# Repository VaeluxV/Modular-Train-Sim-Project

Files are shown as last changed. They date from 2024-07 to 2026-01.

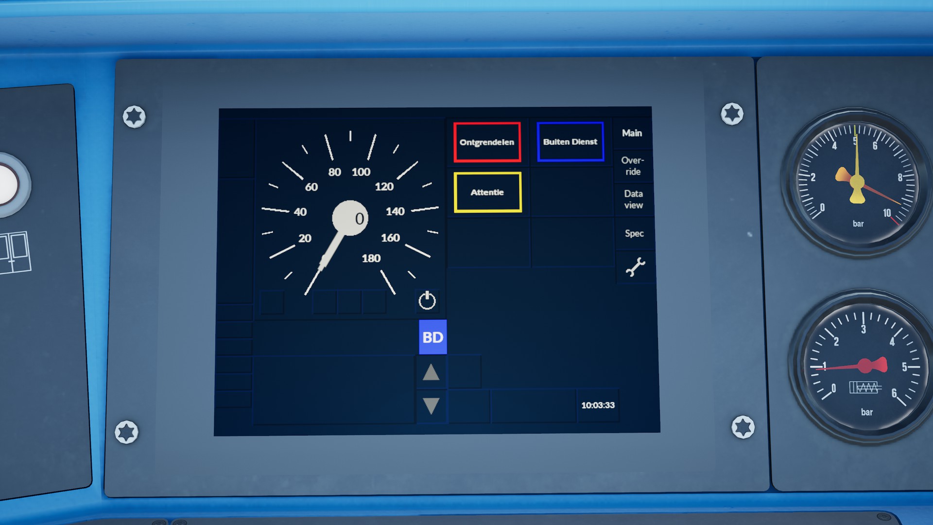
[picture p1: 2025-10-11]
BlenderFiles/Modules/References/20251010132142_1.jpg

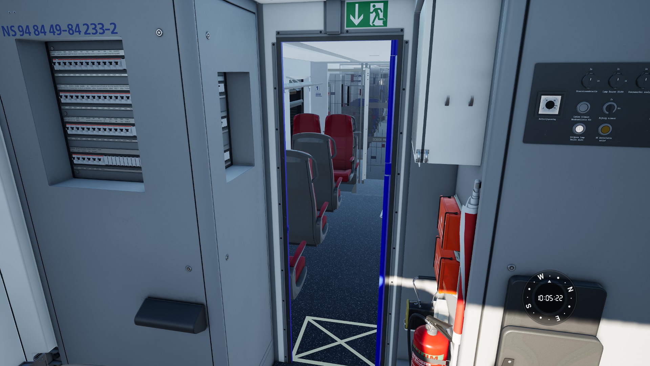
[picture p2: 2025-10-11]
BlenderFiles/Modules/References/20251010132330_1.jpg

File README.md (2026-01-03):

# Modular-Train-Sim-Project
A modular train sim cab project made for arduino. Communicating internally using UART, the main Arduino/Microcontroller requires HID capability (You can use a Pro Mico, Leonardo, etc. for this). 

This is still work in progress. ***This project is currently unfinished!***

<!-- <p xmlns:cc="http://creativecommons.org/ns#" >This work is licensed under <a href="https://creativecommons.org/licenses/by-nc-sa/4.0/?ref=chooser-v1" target="_blank" rel="license noopener noreferrer" style="display:inline-block;">Creative Commons Attribution-NonCommercial-ShareAlike 4.0 International <img style="height:22px!important;margin-left:3px;vertical-align:text-bottom;" src="https://mirrors.creativecommons.org/presskit/icons/cc.svg?ref=chooser-v1" alt=""><img style="height:22px!important;margin-left:3px;vertical-align:text-bottom;" src="https://mirrors.creativecommons.org/presskit/icons/by.svg?ref=chooser-v1" alt=""><img style="height:22px!important;margin-left:3px;vertical-align:text-bottom;" src="https://mirrors.creativecommons.org/presskit/icons/nc.svg?ref=chooser-v1" alt=""><img style="height:22px!important;margin-left:3px;vertical-align:text-bottom;" src="https://mirrors.creativecommons.org/presskit/icons/sa.svg?ref=chooser-v1" alt=""></a></p> --> 

<!-- <p>©VaeluxV</p> -->

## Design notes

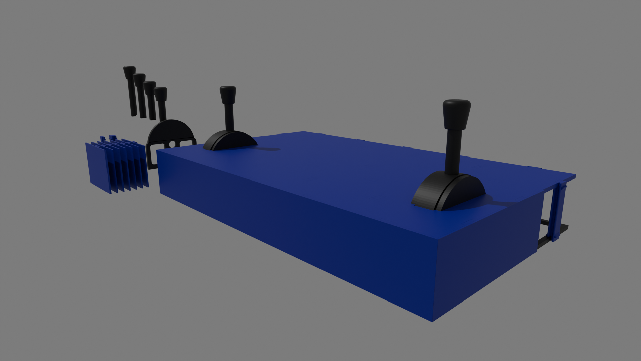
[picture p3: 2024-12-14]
BlenderFiles/Renders/MTS-v0.9.8-Render-2024-12-14-17-46-28.png

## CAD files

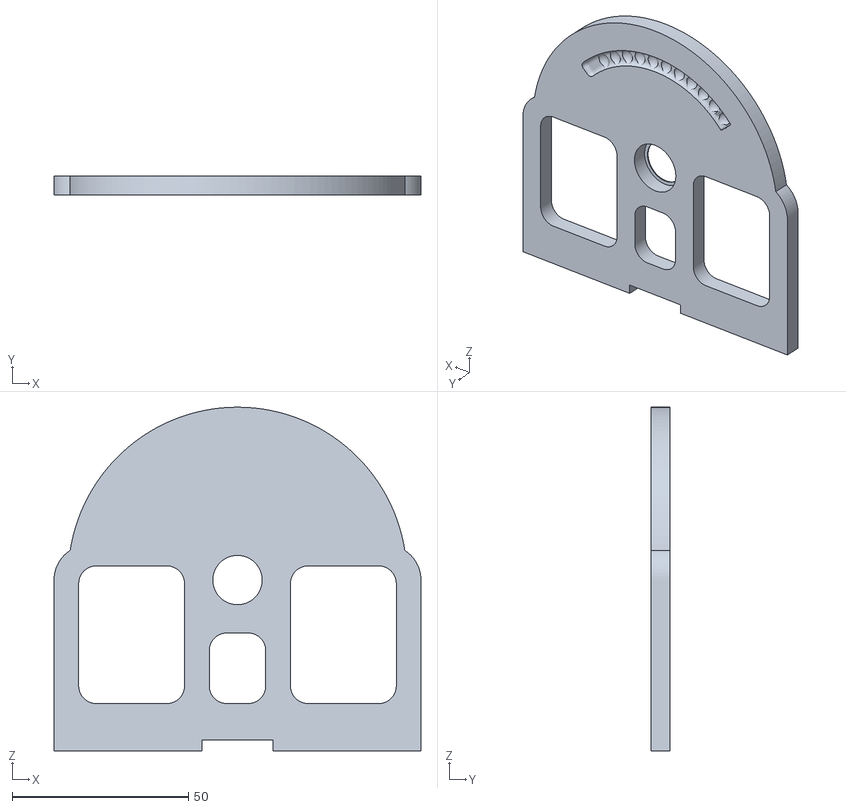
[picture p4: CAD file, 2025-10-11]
BlenderFiles/Modules/STLS/TEST-STL-0.11/Side-Lever-Indents-Flat-TS-v0.11.5.stl
104.0 x 5.40 x 97.4

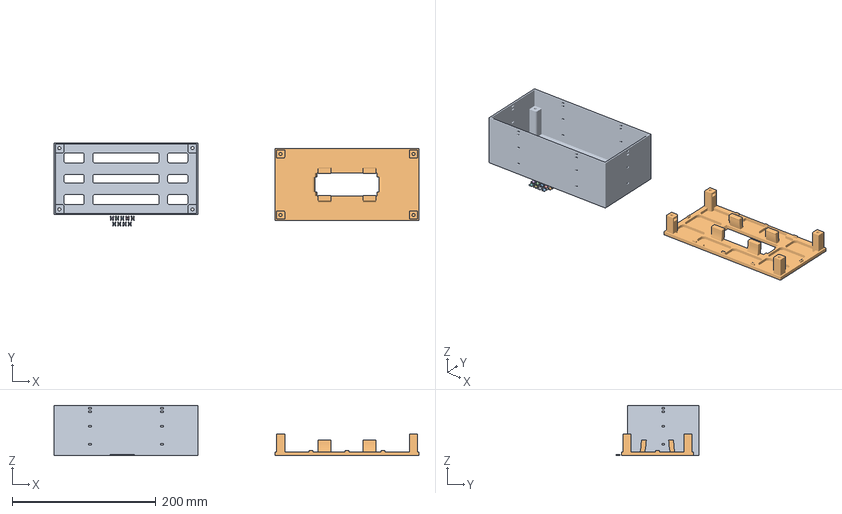
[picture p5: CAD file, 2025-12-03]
BlenderFiles/Modules/STLS/TEST-STL-0.12/TS-Lever-Module-v0.12.3mf
507.2 x 116.0 x 70.0 mm
TS-Bottom-Lever-Module-v0.12.0.stl
TS-Top-Lever-Module-v0.12.0.stl
TS-Clip-Lever-Module-v0.12.0.stl x 9

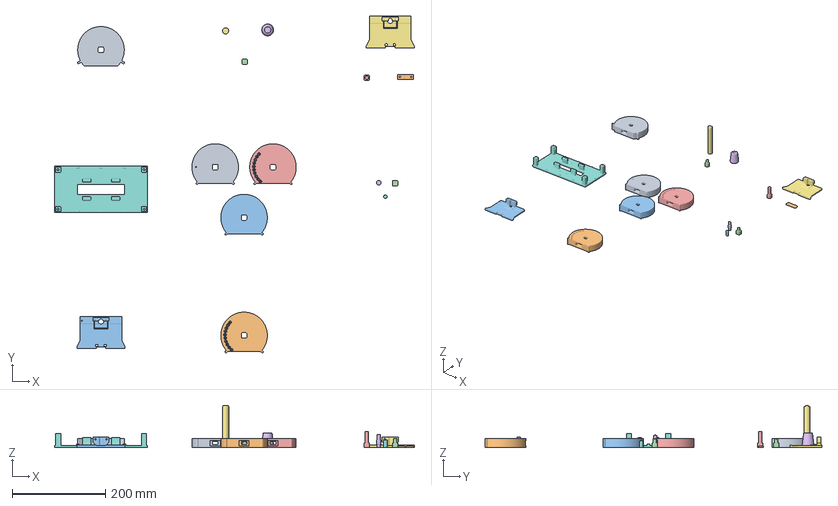
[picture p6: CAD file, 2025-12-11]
BlenderFiles/Modules/STLS/TEST-STL-0.13.x/TS-v0.13.3.3mf
772.9 x 723.2 x 91.1 mm
Lever-Base-TS-v0.13.3.stl
Lever-Base-Brake-Magnet-Layout-TS-v0.13.3.stl x 2
Lever-Side-Normal-Attachment-Magnet-TS-v0.13.3.stl
Lever-Shaft-Attachment-TS-v0.13.3.stl
Lever-Side-Hall-Magnet-Attachment-TS-v0.13.3.stl
Lever-Side-FrictionShaft-TS-v0.13.3.stl
Lever-Shaft-Friction-TS-v0.13.3.stl
Lever-Base-Standard-Magnet-Layout-TS-v0.13.3.stl
Lever-Side-FrictionShaft-Part-TS-v0.13.3.stl
Lever-Base-Standard-No-Magnet-Layout-TS-v0.13.3.stl
Lever-Shaft-OneSide-TS-v0.13.3.stl
Lever-FrictionShaft-OneSide-TS-v0.13.3.stl
Lever-Handle-Top-TS-v0.13.3.stl
Lever-Handle-Base-TS-v0.13.3.stl
Lever-Case-Top-TS-v0.13.3.stl

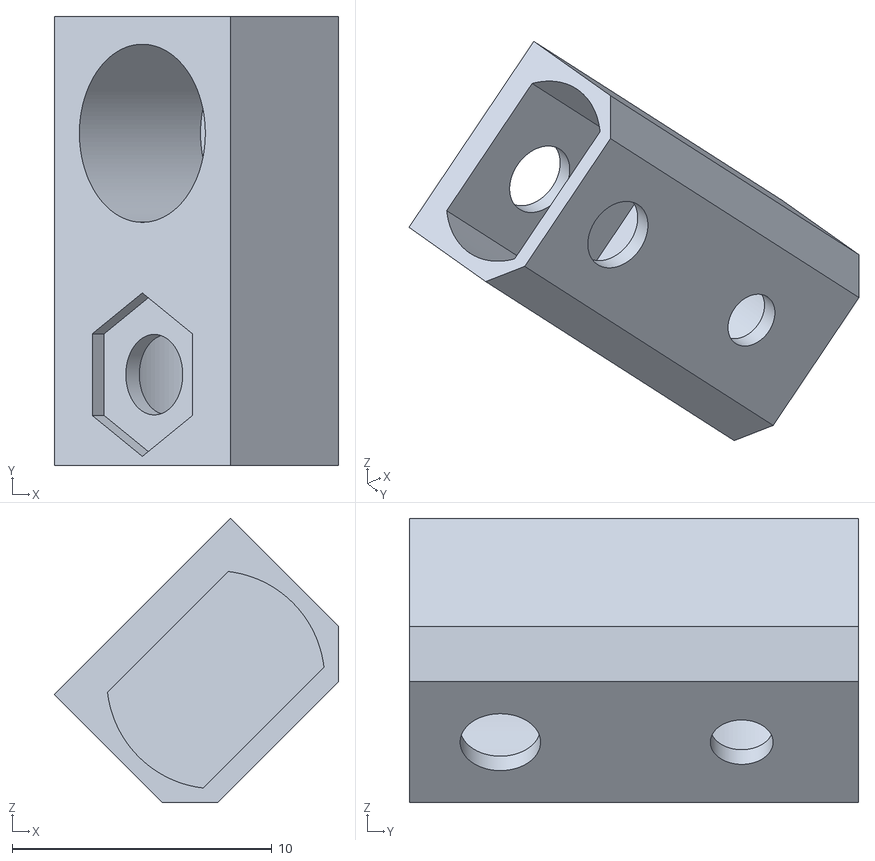
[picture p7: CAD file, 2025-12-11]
BlenderFiles/Modules/STLS/TEST-STL-0.14.x/0.14.0/Lever-Shaft-Magnet-Holder-TSv0.14.0.stl
11.0 x 17.3 x 11.0

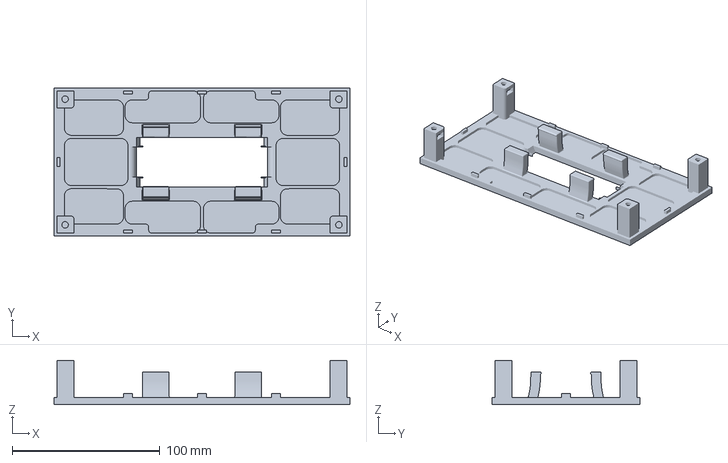
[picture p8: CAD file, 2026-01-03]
BlenderFiles/Modules/STLS/TEST-STL-0.15.x/Lever-Box-TS-v0.15.0.3mf
200.0 x 100.0 x 30.0 mm

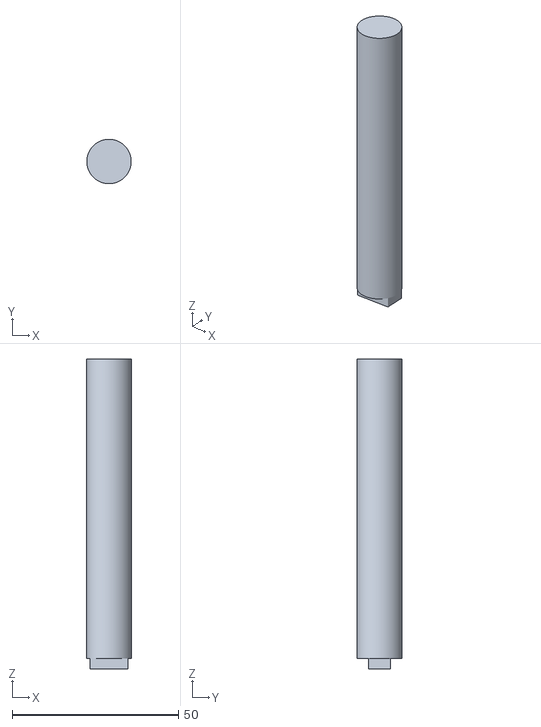
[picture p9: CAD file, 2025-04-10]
BlenderFiles/STLs/v0.10.5/levers_standard/handle_base_filled_long_lever-MTSP-v0.10.5.stl
13.4 x 13.4 x 93.1

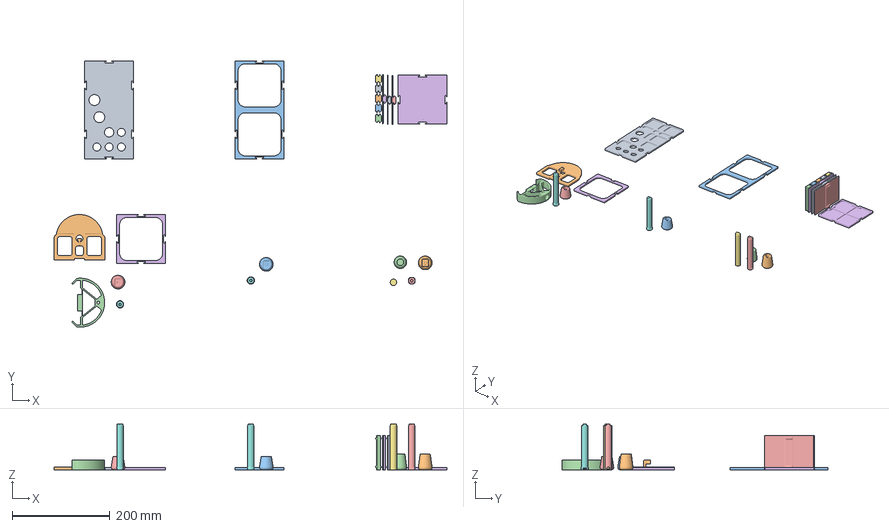
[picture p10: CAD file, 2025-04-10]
BlenderFiles/STLs/v0.10.5/MTSP-v0.10.5.3mf
802.6 x 543.8 x 93.1 mm
top_semi_hollow-MTSP-v0.10.1.stl
handle_top_long_standard_lever-MTSP-v0.10.5.stl
handle_top_standard_lever-MTSP-v0.10.4.stl x 2
handle_top_long_no_button_standard_lever-MTSP-v0.10.5.stl
handle_base_long_lever-MTSP-v0.10.5.stl
base_hollow-MTSP-v0.9.8.stl
handle_base_filled_long_lever-MTSP-v0.10.5.stl
handle_base_long_lever-MTSP-v0.10.4.stl x 2
connector_wall_corner_outer_single-MTSP-v0.9.8.stl x 2
common_side_sensor_lever-MTSP-v0.9.8.stl
bottom_hollow-MTSP-v0.10.1.stl
base_lever-MTSP-v0.10.4.stl
connector_standard-MTSP-v0.9.8.stl x 5
connector_wall-MTSP-v0.9.8.stl
top_semi_hollow-MTSP-v0.9.8.stl

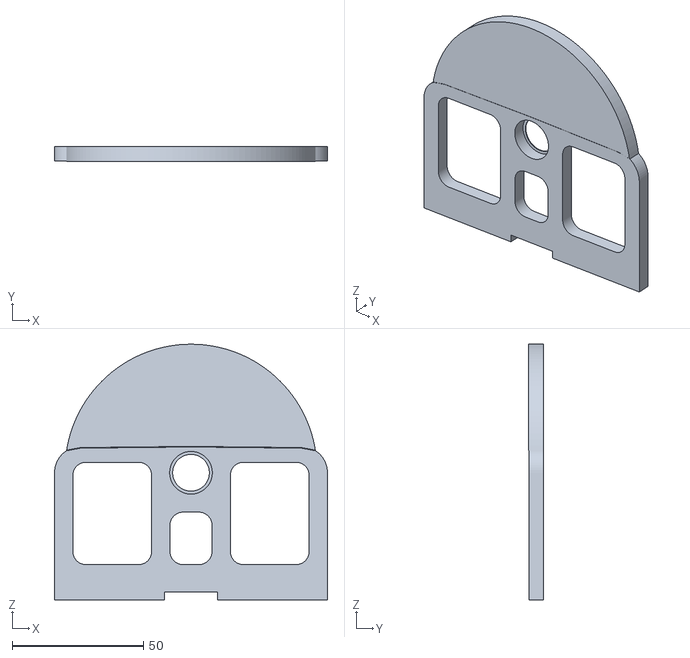
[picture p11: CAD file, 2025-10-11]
BlenderFiles/Modules/STLS/TEST-STL-0.11/Side-Lever-No-Indents-TS-v0.11.5.stl
104.0 x 5.60 x 97.4

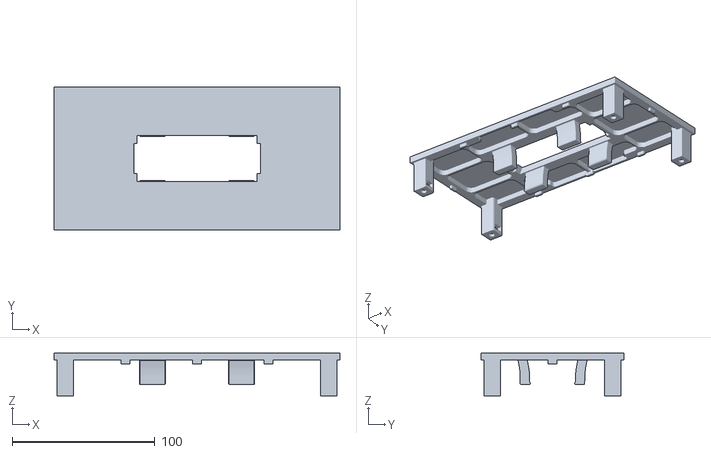
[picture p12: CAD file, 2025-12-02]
BlenderFiles/Modules/STLS/TEST-STL-0.12/TS-Top-Lever-Module-v0.12.0.stl
200.0 x 100.0 x 30.0

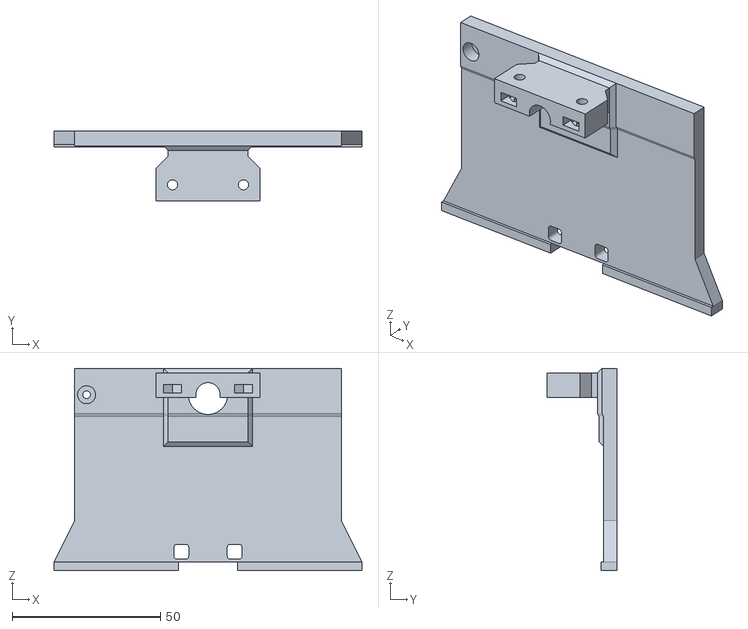
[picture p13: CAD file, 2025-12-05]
BlenderFiles/Modules/STLS/TEST-STL-0.13.x/Lever-Side-Normal-Attachment-Magnet-TS-v0.13.3.stl
104.0 x 23.5 x 68.3

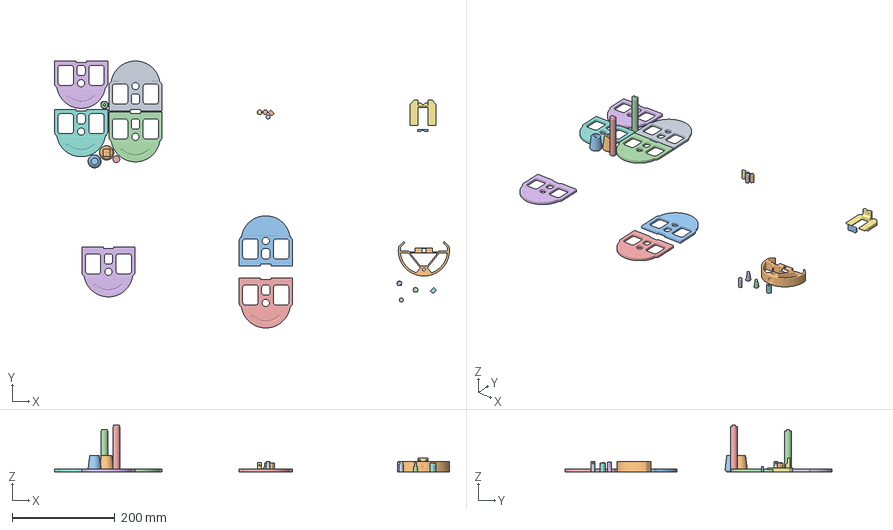
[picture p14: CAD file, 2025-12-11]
BlenderFiles/Modules/STLS/TEST-STL-0.14.x/0.14.0/TSv0.14.0.3mf
770.6 x 520.9 x 91.1 mm
Lever-Base-Side-TSv0.14.0.stl
Lever-Base-Middle-Generic-TSv0.14.0.stl
Lever-Base-Side-Magnets-TSv0.14.0.stl
Lever-Shaft-Friction-Attachment-TSv0.14.0.stl x 2
Lever-Base-Side-Notched-Smooth-TSv0.14.0.stl x 2
Lever-Shaft-Magnet-Attachment-TSv0.14.0.stl x 2
Lever-Shaft-Fricton-Extrusion-TSv0.14.0.stl
Lever-Shaft-Magnet-Holder-TSv0.14.0.stl x 2
Lever-Shaft-Friction-Part-TSv0.14.0.stl x 2
Lever-Shaft-Fricton-Extrusion-Part-TSv0.14.0.stl
Lever-Base-Side-Notched-Brakes-TSv0.14.0.stl
Lever-Base-Side-Notched-Center-TSv0.14.0.stl x 2
Lever-Handle-Button-Top-TSv0.14.0.stl
Lever-Handle-Basic-Top-TSv0.14.0.stl
Lever-Handle-Button-TSv0.14.0.stl
Lever-Handle-Basic-TSv0.14.0.stl

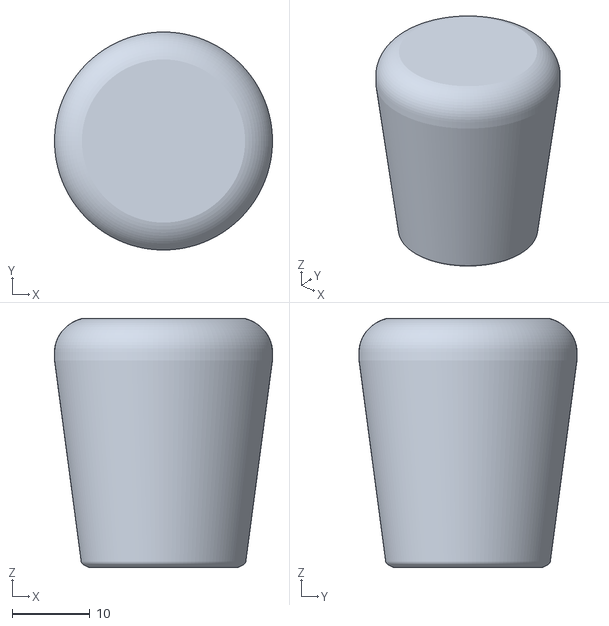
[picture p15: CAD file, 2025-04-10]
BlenderFiles/STLs/v0.10.5/levers_standard/handle_top_long_standard_lever-MTSP-v0.10.5.stl
28.1 x 28.1 x 32.1

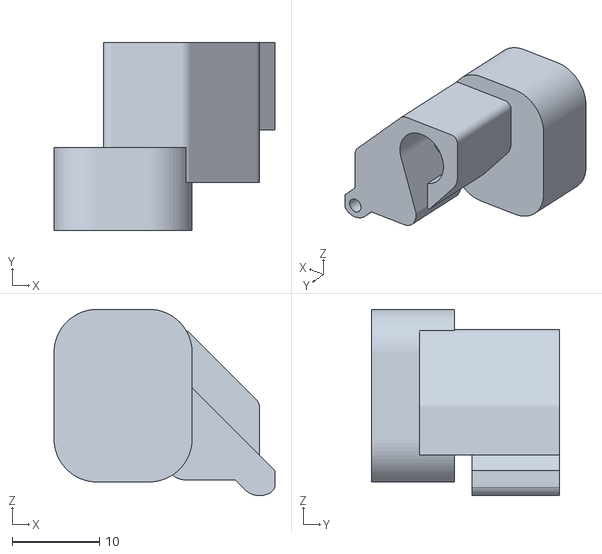
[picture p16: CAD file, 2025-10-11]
BlenderFiles/Modules/STLS/TEST-STL-0.11/Spring-Base-TS-v0.11.4.stl
25.3 x 21.5 x 21.4

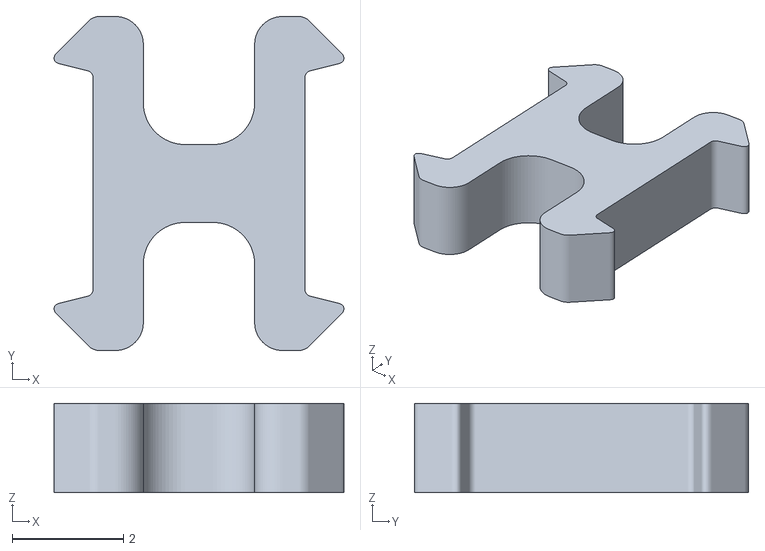
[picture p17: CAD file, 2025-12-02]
BlenderFiles/Modules/STLS/TEST-STL-0.12/TS-Clip-Lever-Module-v0.12.0.stl
5.21 x 6.00 x 1.60

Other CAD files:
BlenderFiles/Modules/STLS/TEST-STL-0.15.x/Top-Lever-Box-TS-v0.15.0.stl
BlenderFiles/Modules/STLS/TEST-STL-0.13.x/Lever-Base-Standard-No-Magnet-Layout-TS-v0.13.3.stl
BlenderFiles/Modules/STLS/TEST-STL-0.14.x/0.14.0/Lever-Shaft-Friction-Attachment-TSv0.14.0.stl
BlenderFiles/STLs/v0.10.5/levers_standard/handle_top_long_no_button_standard_lever-MTSP-v0.10.5.stl
BlenderFiles/Modules/Older versions/TrainSim-v2026.01.03.blend
BlenderFiles/Modules/Older versions/TrainSim-v2026.01.04.blend
BlenderFiles/Modules/Older versions/TrainSim-v2026.01.05.blend
BlenderFiles/Modules/STLS/TEST-STL-0.11/Experimental-TS-v0.11.2.3mf
BlenderFiles/Modules/STLS/TEST-STL-0.11/Experimental-TS-v0.11.5.3mf
BlenderFiles/Modules/STLS/TEST-STL-0.11/Magnet-Connector-TS-v0.11.3.stl
BlenderFiles/Modules/STLS/TEST-STL-0.11/Shaft-Connector-TS-v0.11.0.stl
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

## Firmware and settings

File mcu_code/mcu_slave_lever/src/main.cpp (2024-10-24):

#include <Arduino.h>
#include <FS.h>
#include <SPIFFS.h>
#include <Update.h>
#include <ArduinoJson.h>
#include <painlessMesh.h>

#define FORMAT_SPIFFS_IF_FAILED false

unsigned long previousMillis = 0;   // For tracking time between updates
unsigned long updateInterval = 100; // Update interval in ms (0.1 second)

int rawSensor0Data;     // For storing the raw sensor data
int prevRawSensor0Data; // For storing the previous sensor data

int processedSensor0Data;     // For storing the processed sensor data (example: smoothed out data)
int prevProcessedSensor0Data; // For storing previous state of processed sensor data. Used for the program to know if it needs to send new sensor data or not

int sensor0Percentage;
int prevSensor0Percentage;

int sensor0Pin; // The physical pin for sensor 0
int sensor0Smoothing; // How much smoothin will be applied to sensor 0
int sensor0MinValue; // The min reading of sensor 0 when lever is all the way at the minimum point
int sensor0MaxValue; // The max reading of sensor 0 when lever is all the way at the maximum point

int sensorUpdateRate; // How many readings per second you want the sensors to take. Default: 60, you can change this in the config.

/* ---  Mesh data  --- */
String meshName;
String meshPassword;
String deviceType;
String deviceID;

int meshPort;
/* --- --- --- --- --- */

painlessMesh mesh;

// Define custom functions to prevent issues with the order of these
void loadConfig();

void setupMesh();
void receivedCallback(uint32_t from, String &msg);
void newConnectionCallback(uint32_t nodeId);
void sendMessageToMesh(String msg);
float smoothSensorData(int sensorDataIn, int decimals, int readingListLength);
void sensorReading();

// Loads and parses the configuration (config.json) file
void loadConfig()
{
  // Open the configuration file
  File configFile = SPIFFS.open("/config.json", "r");
  String fileContent = "";
  if (!configFile)
  {
    Serial.println("Failed to open config file for reading");
    return;
  }

  while (configFile.available())
  {
    fileContent += (char)configFile.read();
  }
  configFile.close();

  Serial.println(fileContent);

  // Create a JSON document
  JsonDocument doc; // Increase size if necessary

  DeserializationError error = deserializeJson(doc, fileContent);

  if (error)
  {
    Serial.print("deserializeJson() failed: ");
    Serial.println(error.c_str());
    return;
  }

  meshName = doc["meshName"].as<String>();              // "traincabmesh" by default, please change this in the config.json file
  meshPassword = doc["meshPassword"].as<String>();      // "traincabmesh_ABCDEFG123456" by default, please change this in the config.json file
  meshPort = doc["meshPort"].as<int>();                 // Port for the mesh network, has to be the same on all devices.
  deviceType = doc["deviceType"].as<String>();          // "slave" or "master"
  deviceID = doc["deviceID"].as<String>();              // Unique device ID
  sensorUpdateRate = doc["sensorUpdateRate"].as<int>(); // Get the sensor update rate (in times per second), 120 by default
  sensor0Pin = doc["sensor0Pin"].as<int>();             // Sensor 0 physical pin connection
  sensor0Smoothing = doc["sensor0Smoothing"].as<int>(); // Sensor 0 smoothing amount
  sensor0MinValue = doc["sensor0MinValue"].as<int>();   // Sensor 0 min value
  sensor0MaxValue = doc["sensor0MaxValue"].as<int>();   // Sensor 0 max value
}

// Initialize mesh network
void setupMesh()
{
  mesh.setDebugMsgTypes(ERROR | STARTUP | CONNECTION);         // Enable debugging
  mesh.init(meshName.c_str(), meshPassword.c_str(), meshPort); // Initialize mesh with name, password, and port 5555
  mesh.onReceive(&receivedCallback);                           // Set callback for receiving messages
  mesh.onNewConnection(&newConnectionCallback);                // Set callback for new connections
}

void receivedCallback(uint32_t from, String &msg)
{
  Serial.printf("Received message from %u: %s\n", from, msg.c_str());
}

// Callback when a new node connects
void newConnectionCallback(uint32_t nodeId)
{
  Serial.printf("New connection, nodeId = %u\n", nodeId);
}

// Send a message to the mesh network
void sendMessageToMesh(String msg)
{
  mesh.sendBroadcast(msg.c_str()); // Broadcast message to all connected devices
}

/*
sensorDataIn -> input raw sensor data value

decimals -> how many numbers behind the decimal poin should the function return?
(Example: decimals = 1 will result in values such as: 1.5, 81.1 | decimals = 3 will result in values such as: 24.348, 67.157)

readingListLength determines how many readings will be kept and will in turn influence the responsiveness and smoothness. I recommend keeping this as low as possible;
test this and see at what point the processed sensor data stays stable when the lever is not moved. Higher values = smoother but less responsive.
*/
float smoothSensorData(int sensorDataIn, int decimals, int readingListLength) {
    // Static variables to store previous readings and the current index
    static float *readings = nullptr;
    static int index = 0;
    static bool initialized = false;

    // Initialize the readings array only once
    if (!initialized) {
        readings = new float[readingListLength]();
        initialized = true;
    }

    // Add new sensor data to the readings array at the current index
    readings[index] = sensorDataIn;

    // Update the index and wrap around if necessary
    index = (index + 1) % readingListLength;

    // Calculate the sum of all readings in the array
    float sum = 0.0;
    for (int i = 0; i < readingListLength; i++) {
        sum += readings[i];
    }

    // Calculate the average value
    float average = sum / readingListLength;

    // Calculate the rounding factor based on the specified decimal places
    float roundingFactor = pow(10, decimals);

    // Round the average to the specified number of decimal places
    return round(average * roundingFactor) / roundingFactor;
}



void sensorReading()
{
  static unsigned long lastReadTime = 0;
  if (millis() - lastReadTime > (1000 / sensorUpdateRate)) // Run set amount of times per second, default: 60 times per second, to change this: change "sensorUpdateRate" in config.json
  {
    // Read the sensors
    rawSensor0Data = analogRead(sensor0Pin);

    // Process sensor data
    processedSensor0Data = smoothSensorData(rawSensor0Data, 1, sensor0Smoothing);

    sensor0Percentage = map(processedSensor0Data, sensor0MinValue, sensor0MaxValue, 0, 100);

    if (sensor0Percentage != prevSensor0Percentage)
    {
      // Send message containing info to master
      // Serial.println("Sensor data changed");
      
      Serial.println(sensor0Percentage);
    }

    // prevRawSensor0Data = rawSensor0Data;
    // prevProcessedSensor0Data = processedSensor0Data;
    prevSensor0Percentage = sensor0Percentage;

    lastReadTime = millis();
  }
}

void setup()
{
  Serial.begin(115200); // Start serial communication

  // Start SPIFFS
  if (!SPIFFS.begin(FORMAT_SPIFFS_IF_FAILED))
  {
    Serial.println("SPIFFS mount failed!");
    return;
  }

  loadConfig(); // Load config from "config.json" in SPIFFS

  // Debug print config info
  Serial.print("Mesh name: ");
  Serial.println(meshName.c_str());

  Serial.print("Mesh password: ");
  Serial.println(meshPassword.c_str());

  Serial.print("Mesh port: ");
  Serial.println(meshPort);

  Serial.print("Device type: ");
  Serial.println(deviceType.c_str());

  Serial.print("Device ID: ");
  Serial.println(deviceID.c_str());

  setupMesh(); // Initialize mesh network

  pinMode(sensor0Pin, INPUT);
}

void loop()
{
  mesh.update(); // Handle mesh tasks

  sensorReading();

  // Send a test message every 10 seconds
  static unsigned long lastSentTime = 0;
  if (millis() - lastSentTime > 10000)
  {
    String message = "Hello from " + deviceType + " " + deviceID;
    sendMessageToMesh(message);
    lastSentTime = millis();
  }
}

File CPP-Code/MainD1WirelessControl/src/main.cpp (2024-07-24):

#include <Arduino.h>
#include <painlessMesh.h>
#include <ArduinoJson.h>

#define MESH_SSID "TrainSimCabMeshNet" // Set your mesh network name
#define MESH_PASSWORD "SecurePassword123" // Set your mesh password
#define MESH_PORT 5555 // Port for communication, default is 5555

#define NODE_NAME "node_main"

// Create an instance of the painlessMesh object
painlessMesh mesh;

void setup() {
    Serial.begin(9600); // Initialize serial communication
    Serial.println("Starting Mesh Network...");

    // Initialize mesh
    mesh.init(MESH_SSID, MESH_PASSWORD, MESH_PORT);
    
    // Set the node name (optional)
    mesh.setHostname(NODE_NAME); // Set the node name
    
    // Callback when a message is received
    mesh.onReceive([](uint32_t from, String &msg) {
        Serial.printf("Message received from node %u: %s\n", from, msg.c_str());
    });

    // Start periodic message sending
    mesh.onNewConnection([](uint32_t nodeId) {
        Serial.printf("New connection established with node %u\n", nodeId);
    });

    mesh.onDroppedConnection([](uint32_t nodeId) {
        Serial.printf("Dropped connection with node %u\n", nodeId);
    });
}

void loop() {
    mesh.update(); // Keep the mesh network updated

    // Send a message every 16 milliseconds (about 60 times per second)
    static unsigned long lastSendTime = 0;
    unsigned long currentTime = millis();
    
    if (currentTime - lastSendTime >= 16) {
        String message = "Hello from main node!";
        mesh.sendBroadcast(message); // Send message to all nodes in the mesh
        lastSendTime = currentTime;
        Serial.println("Message sent: " + message);
    }

    // You can adjust the message frequency here if needed
    // For 120 messages per second, use 8 milliseconds
}

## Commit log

2024-07-23 Updated AMP to receive more vars
    Updated AMP to receive more vars like throttle, brake, reverser, etc.
    Also added specific control files (unfinished)
    [main.cpp]
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2024-08-27 Add initial Blender file
    [TrainSim.blend]
2024-08-27 small tweak
    [TrainSim.blend]
2024-09-16 Add basic connector part
    Added basic connector part with a base size of 100mm (10cm) for general use throughout the project
    [TrainSim.blend]
2024-10-19 Add new master mcu code
    This code is unfinished and currently only reads the config file from SPIFFS.
    The mesh network and other functionality will be added soon.
2024-10-20 Initial commit for slave device code
    Currently all code is a copy of the master, will be changed soon.
2024-10-20 Fix leftover include
    Removed an include that was leftover from testing and was no longer needed.
    [main.cpp]
2024-10-20 Added more configurable options
    Added more configurable options such as sensor pin and update rate.
    Preparing code to read said sensor(s) in a semi-modular way.
2024-10-20 Added sensor reading function and settings
    Added a proper sensor reading function and settings for the reading of said sensor, as well as made the sensor only send data (currently substituted by a Serial.println();) whenever the value percent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
2024-10-28 Adjust fitment and finish
    Adjusted fitment after printing parts multiple times (using a Bambu Lab P1S, results on other printers may vary and need adjusting)
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2024-11-03 Add STLs, 3mf files and tweaked models
    [base_hollow-MTSP-v0.9.8.stl, base_hollow_2x1_lever-MTSP-v0.9.8.stl, base_lever-MTSP-v0.9.8.stl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]
2024-12-31 Add button/switch covers/holder pieces
    [base_hollow-MTSP-v0.9.8.stl, base_hollow_2x1_lever-MTSP-v0.9.8.stl, base_lever-MTSP-v0.9.8.stl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]
2024-12-31 fixed exports of button parts
2025-01-02 Add 3mf collection for expanders + tweaks
    [base_hollow-MTSP-v0.9.8.stl, expanders-MTSP-v0.9.10.3mf, top_semi_hollow-MTSP-v0.9.8.stl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]
2025-01-22 Added Improved Brake lever, buttons, + more
    Added Improved Brake lever, buttons, anti-slip and tweaks to existing parts
    [base_hollow-MTSP-v0.9.8.stl, base_hollow_2x1_lever-MTSP-v0.9.8.stl, base_hollow_anti_slip_feet-MTSP-v0.9.8.stl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]
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2025-01-22 Fixed missing faces in new brake lever piece
    [expanders-MTSP-v0.9.13.3mf, unique_side_air_brake_lever-MTSP-v0.9.13.stl]
2025-01-22 Added secondary "spring" to the brake lever
    [expanders-MTSP-v0.9.13.3mf, handle_top_standard_lever-MTSP-v0.9.13.stl, unique_side_air_brake_lever_marker-MTSP-v0.9.13.stl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]
2025-01-23 Added more variations of springs
    Added more variations of springs, not fully working as intended, will update further
    [Prints-MTSP-v0.9.13.3mf, lever_mount_plate_external_device_empty-MTSP-v0.9.13.stl, unique_side_air_brake_lever_return_S_L-MTSP-v0.9.13.stl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]
2025-04-09 Added a wider button expander
    Added a wider button expander with extra cutouts for levers
    [bottom_hollow-MTSP-v0.10.1.stl, top_semi_hollow-MTSP-v0.10.1.stl]
2025-04-10 Add new lever with integrated button
    Added a new lever with integrated button. Removed the .blend1 files and sorted older versions into a separate folder.
    [MTSP-v0.10.1.3mf, MTSP-v0.10.4.3mf, base_lever-MTSP-v0.10.4.stl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]
2025-04-10 Fixed new levers button functionality
    [MTSP-v0.10.5.3mf, base_lever-MTSP-v0.10.4.stl, handle_base_long_lever-MTSP-v0.10.5.stl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]
2025-04-10 Added longer lever tops and fixes
    [MTSP-v0.10.5.3mf, handle_base_filled_long_lever-MTSP-v0.10.5.stl, handle_top_long_no_button_standard_lever-MTSP-v0.10.5.stl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]
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2025-10-10 Add references for NS SNG and ICMm modules
    Add reference materials for NS SNG and ICMm based modules
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2025-10-10 Add spring system
    Add spring system designed for a spring from clothes pins
    [Experimental-TS-v0.11.2.3mf, Magnet-Connector-TS-v0.11.0.stl, Sensor-holder-TS-v0.11.0.stl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]
2025-10-10 Fixed magnet holder tolerances
    [Magnet-Connector-TS-v0.11.3.stl]
2025-10-10 Tweaked tolerances, added more side plates
    [Experimental-TS-v0.11.5.3mf, Magnet-Connector-TS-v0.11.0.stl, Sensor-holder-TS-v0.11.0.stl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]
2025-12-01 Updated module design + fixed manifold issues
    [TS-Test-v0.12.0.stl]
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2025-12-01 Lever module tweaked + test exports
    Lever module tweaked + test exports + moved older file to correct location
    [TS-Bottom-Lever-Module-v0.12.0.stl, TS-Top-Lever-Module-v0.12.0.stl]
2025-12-01 Reworked bottom part
    [TS-Bottom-Lever-Module-v0.12.0.stl]
2025-12-01 re-added cutouts for lever mechanism on bottom
    [TS-Bottom-Lever-Module-v0.12.0.stl]
2025-12-02 Added connector clips and cutouts
    [TS-Bottom-Lever-Module-v0.12.0.stl, TS-Clip-Lever-Module-v0.12.0.stl, TS-Lever-Module-v0.12.3mf]
2025-12-02 Edit top for more screw lengths
    Multiple lengths of M4 screws should work now
    [TS-Top-Lever-Module-v0.12.0.stl]
2025-12-02 Add tabs to hold sides from buckling inwards
    [TS-Top-Lever-Module-v0.12.0.stl]
2025-12-03 Add initial button panel parts + remove old parts
    [TS-Lever-Module-v0.12.3mf]
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2025-12-03 Tweaks + test stl exports
    [Lever-Base-TS-v0.13.3.stl, Lever-Handle-Base-TS-v0.13.3.stl, Lever-Handle-Top-TS-v0.13.3.stl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]
2025-12-04 Make friction part stronger + lever base fixes
    [Lever-Base-TS-v0.13.3.stl, Lever-Case-Bottom-TS-v0.13.3.stl, Lever-Case-Top-TS-v0.13.3.stl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]
2025-12-04 Added magnet/hall effect module
    [Lever-Handle-Top-TS-v0.13.3.stl, Lever-Side-FrictionShaft-Part-TS-v0.13.3.stl, Lever-Side-Hall-Magnet-Attachment-TS-v0.13.3.stl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]
2025-12-04 Reworked friction system
    [Lever-Case-Top-TS-v0.13.3.stl, Lever-Handle-Top-TS-v0.13.3.stl, Lever-Shaft-Attachment-TS-v0.13.3.stl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]
2025-12-05 Add magnet positions
    [Lever-Base-Brake-Magnet-Layout-TS-v0.13.3.stl, Lever-Base-Standard-Magnet-Layout-TS-v0.13.3.stl, Lever-Base-Standard-No-Magnet-Layout-TS-v0.13.3.stl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]
2025-12-11 Switch back to original lever design +
    Switch back to original lever design, but with the new friction part added onto that instead
    [Lever-Base-Side-Notched-Brakes-TSv0.14.0.stl, Lever-Base-Side-Notched-Center-Ends-TSv0.14.0.stl, Lever-Base-Side-Notched-Center-TSv0.14.0.stl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]
2025-12-11 Fixes for sides
    [Lever-Base-Side-Magnets-TSv0.14.0.stl, Lever-Base-Side-Notched-Center-Ends-TSv0.14.0.stl, Lever-Base-Side-Notched-Center-TSv0.14.0.stl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]
2025-12-11 Revised Handle Base
    [Lever-Base-Middle-Generic-TSv0.14.0.stl, Lever-Shaft-Friction-Attachment-TSv0.14.0.stl, Lever-Shaft-Friction-Part-TSv0.14.0.stl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]
2026-01-03 Update lever top to add spacing
    [Top-Lever-Box-TS-v0.15.0.stl]
2026-01-03 Add 3mf file
    [Lever-Box-TS-v0.15.0.3mf]
2026-01-03 Started a completely fresh version
    Started working on a completely fresh version built from the ground up. The previous version was too much of a mess to continue with.
    [TrainSim-v2026.01.03.blend]
2026-01-03 Move old version and remove .blend1
    [TrainSim-v2026.01.03.blend]
2026-01-04 Add bearings and basics
    [TrainSim-v2026.01.03.blend, TrainSim-v2026.01.04.blend]
2026-01-04 Add basic case and parts
    [TrainSim-v2026.01.04.blend]
2026-01-04 Add connector
    [TrainSim-v2026.01.04.blend, TrainSim-v2026.01.05.blend]
2026-01-08 Add (Testing) Connectors
    [TrainSim-v2026.01.05.blend, TrainSim-v2026.01.08.blend]
